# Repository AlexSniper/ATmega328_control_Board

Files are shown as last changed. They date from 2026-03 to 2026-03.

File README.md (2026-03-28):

# ATmega328 Control Board

Custom embedded control board based on the ATmega328PU microcontroller, designed in KiCad and compatible with Arduino firmware.

## Prototype Board
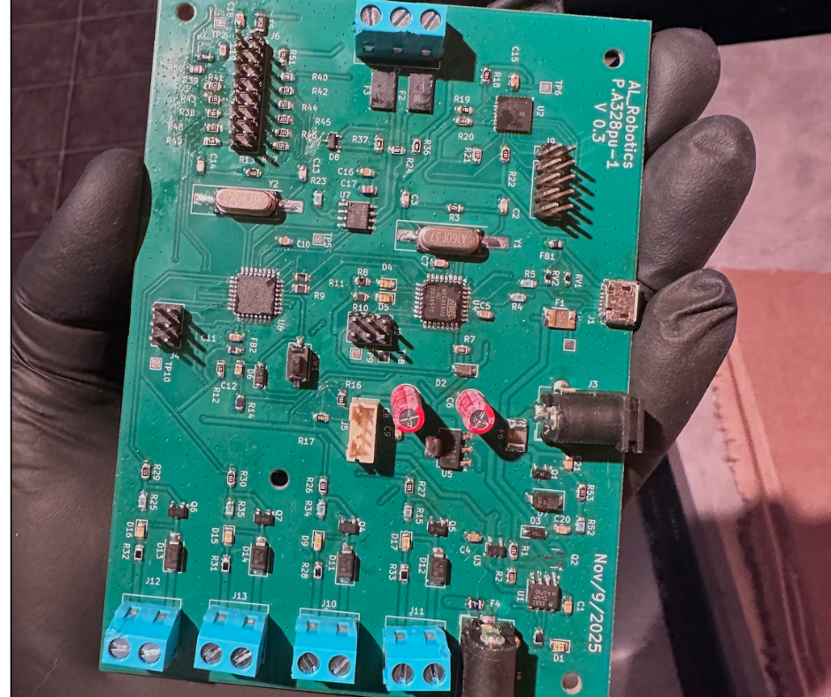
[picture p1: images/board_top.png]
ATmega328 Control Board


## Assembly
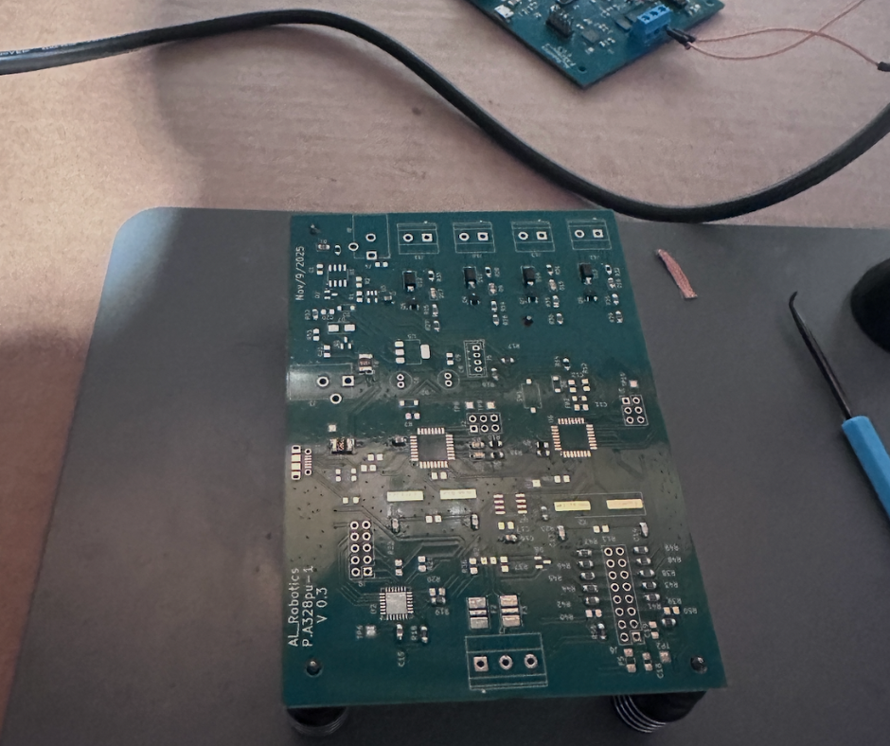
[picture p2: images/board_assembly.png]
Board Assembly


## Testing Setup
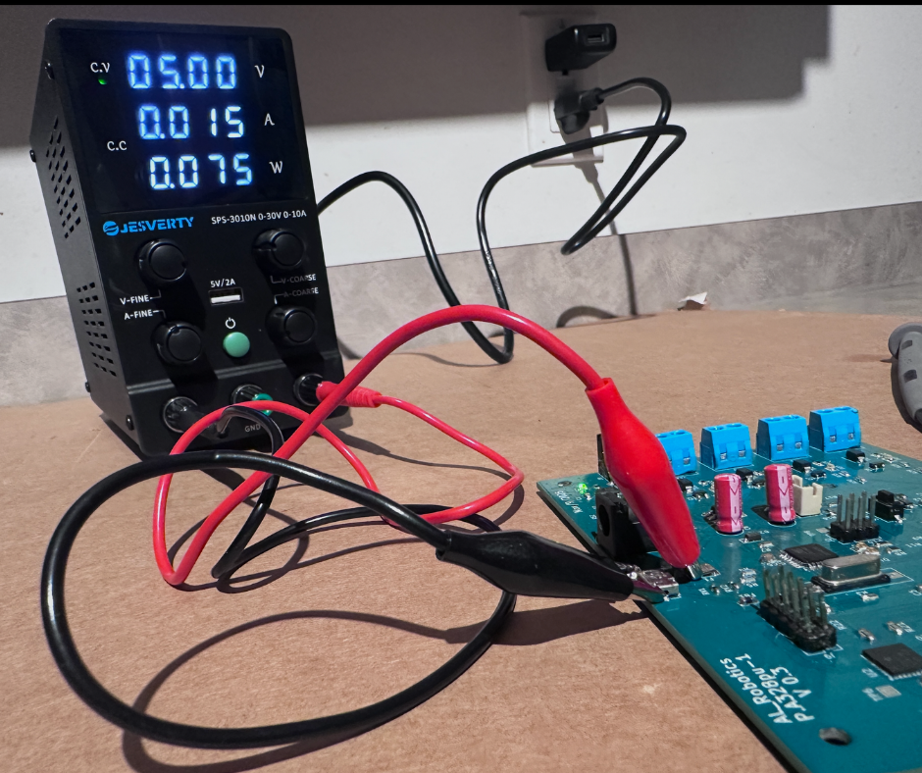
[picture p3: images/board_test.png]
Board Testing


## Clock Verification
External 16 MHz crystal verified using oscilloscope.

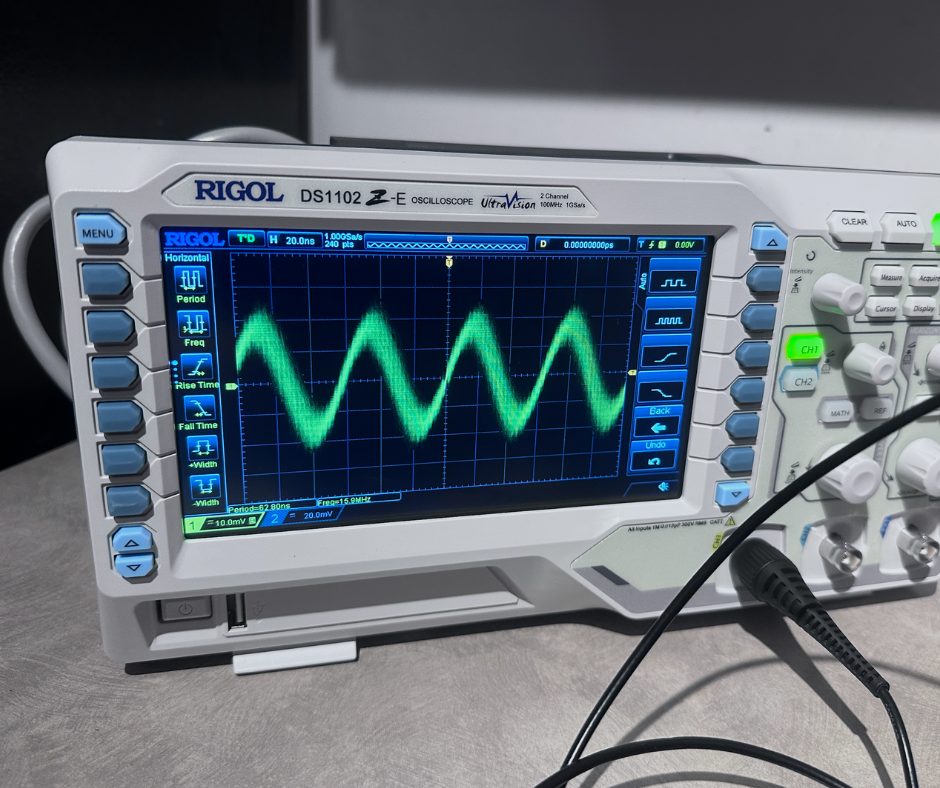
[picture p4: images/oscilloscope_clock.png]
Oscilloscope Clock


## Power Testing
Board powered and tested using laboratory power supply.

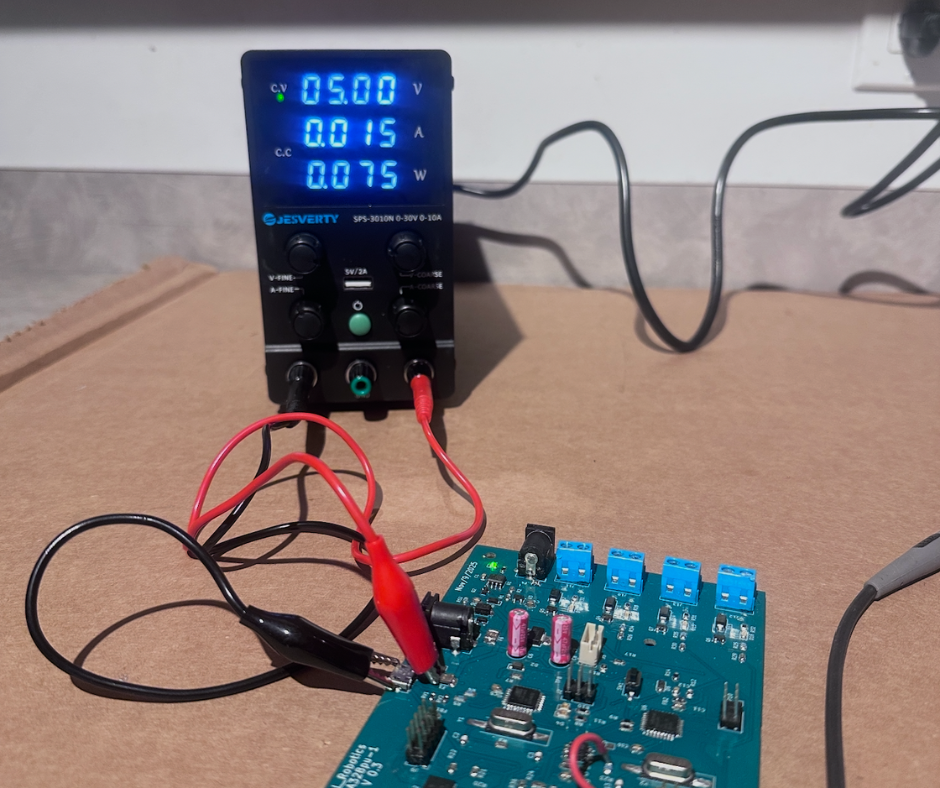
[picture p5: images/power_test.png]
Power Test


## LCD Interface Test
16×2 LCD connected to the ATmega328 board to verify digital IO functionality and firmware operation.
Display output confirms correct microcontroller operation.

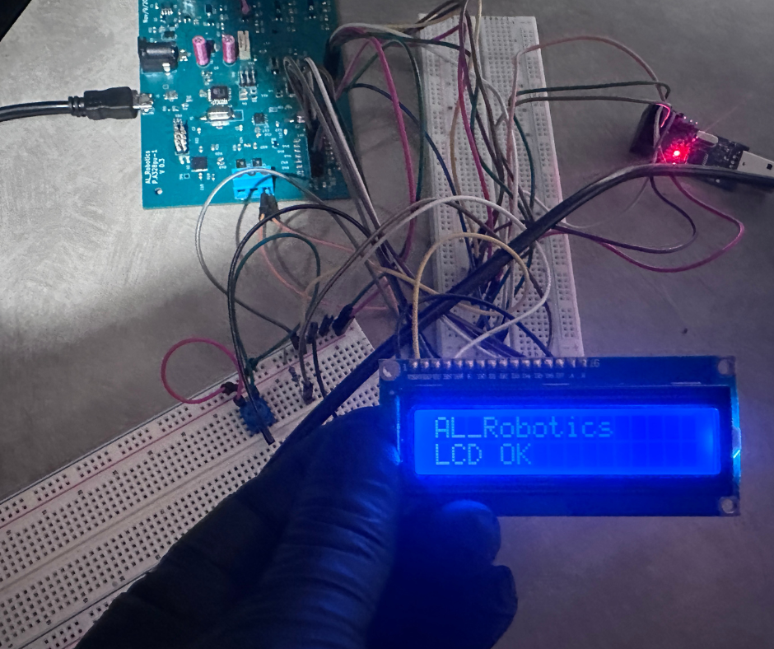
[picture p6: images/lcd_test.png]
Power Test
.png)

### Features
- ATmega328PU microcontroller
- 16 MHz external crystal
- MOSFET output drivers
- Screw terminal IO
- USB programming interface
- External power supply

## Repository structure

hardware – KiCad PCB design  
firmware – Arduino firmware  
gerbers – manufacturing files  
bom – bill of materials  
docs – schematic PDF  
images – hardware prototype photos

## Hardware validation

Clock oscillator verified with oscilloscope.

Board powered and tested using laboratory power supply.

## Hardware Revision History

v0.1 – Initial prototype PCB  
v0.2 – Improved routing and component placement  
v0.3 – Stable prototype, validated clock and power supply

## Author

AL Robotics

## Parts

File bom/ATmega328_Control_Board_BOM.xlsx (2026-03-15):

Reference | Qty | Value | MANUFACTURER # | Link | Footprint
C1,C7,C9,C10,C11,C12,C18,C19,C20 | 9 | 100nF | KAF21BR71H104JM | https://www.mouser.ca/ProductDetail/KYOCERA-AVX/KAF21BR71H104JM?qs=Jm2GQyTW%2FbjLJnSOuM%2FLDw%3D%3D | Capacitor_SMD:C_0805_2012Metric_Pad1.18x1.45mm_HandSolder (https://www.mouser.ca/ProductDetail/KYOCERA-AVX/KAF21BR71H104JM?qs=Jm2GQyTW%2FbjLJnSOuM%2FLDw%3D%3D)
C2,C3,C13,C14 | 4 | 22pF | C0805C220M5HACTU | https://www.mouser.ca/ProductDetail/KEMET/C0805C220M5HACTU?qs=W0yvOO0ixfFRsdd8NMWzNA%3D%3D | Capacitor_SMD:C_0805_2012Metric_Pad1.18x1.45mm_HandSolder (https://www.mouser.ca/ProductDetail/KEMET/C0805C220M5HACTU?qs=W0yvOO0ixfFRsdd8NMWzNA%3D%3D)
C4,C5 | 2 | 1uF | CL21B105KBFNNNE | https://www.mouser.ca/ProductDetail/Samsung-Electro-Mechanics/CL21B105KBFNNNE?qs=yOVawPpwOwmddQEBPU6Y9A%3D%3D | Capacitor_SMD:C_0805_2012Metric_Pad1.18x1.45mm_HandSolder (https://www.mouser.ca/ProductDetail/Samsung-Electro-Mechanics/CL21B105KBFNNNE?qs=yOVawPpwOwmddQEBPU6Y9A%3D%3D)
C6,C8 | 2 | 47uF | 860020472006 | https://www.mouser.ca/ProductDetail/Wurth-Elektronik/860020472006 | Capacitor_THT:C_Radial_D5.0mm_H11.0mm_P2.00mm (https://www.mouser.ca/ProductDetail/Wurth-Elektronik/860020472006)
C15,C16 | 2 | 0.1uF | KAF21BR71H104JM | https://www.mouser.ca/ProductDetail/KYOCERA-AVX/KAF21BR71H104JM?qs=Jm2GQyTW%2FbjLJnSOuM%2FLDw%3D%3D | Capacitor_SMD:C_0805_2012Metric_Pad1.18x1.45mm_HandSolder (https://www.mouser.ca/ProductDetail/KYOCERA-AVX/KAF21BR71H104JM?qs=Jm2GQyTW%2FbjLJnSOuM%2FLDw%3D%3D)
C17 | 1 | 10uF | CL21A106KAYNNNE | https://www.mouser.ca/ProductDetail/Samsung-Electro-Mechanics/CL21A106KAYNNNE?qs=yOVawPpwOwmTXAd4dJtNjA%3D%3D | Capacitor_SMD:C_0805_2012Metric_Pad1.18x1.45mm_HandSolder (https://www.mouser.ca/ProductDetail/Samsung-Electro-Mechanics/CL21A106KAYNNNE?qs=yOVawPpwOwmTXAd4dJtNjA%3D%3D)
C21 | 1 | 10nF | KAF21BR71H103KT | https://www.mouser.ca/ProductDetail/KYOCERA-AVX/KAF21BR71H103KT?qs=OcgtsXO%252B3gvXyW8UIvHhiw%3D%3D | Capacitor_SMD:C_0805_2012Metric_Pad1.18x1.45mm_HandSolder (https://www.mouser.ca/ProductDetail/KYOCERA-AVX/KAF21BR71H103KT?qs=OcgtsXO%252B3gvXyW8UIvHhiw%3D%3D)
D1,D4,D5,D9,D15,D16,D17 | 7 | LED | LTST-C170GKT | https://www.mouser.ca/ProductDetail/LITEON/LTST-C170GKT | Diode_SMD:D_0805_2012Metric_Pad1.15x1.40mm_HandSolder (https://www.mouser.ca/ProductDetail/LITEON/LTST-C170GKT)
D2,D6 | 2 | MMSD4148T1G | MMSD4148T1G | https://www.digikey.ca/en/products/detail/onsemi/MMSD4148T1G/919705 | Diode_SMD:D_SOD-123 (https://www.digikey.ca/en/products/detail/onsemi/MMSD4148T1G/919705)
D3 | 1 | B5819W | B5819W | https://www.digikey.ca/en/products/detail/good-ark-semiconductor/B5819W/18648698 | Diode_SMD:D_SOD-123 (https://www.digikey.ca/en/products/detail/good-ark-semiconductor/B5819W/18648698)
D7 | 1 | SMAJ6.0A | SMAJ6.0A | https://www.digikey.ca/en/products/detail/littelfuse-inc/SMAJ6-0A/762252?gclsrc=aw.ds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 | Diode_SMD:D_SMA (https://www.digikey.ca/en/products/detail/littelfuse-inc/SMAJ6-0A/762252?gclsrc=aw.ds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)
D8 | 1 | CDSOT23-SM712 | CDSOT23-SM712 | https://www.digikey.ca/en/products/detail/bourns-inc/cdsot23-sm712/1630592 | Package_TO_SOT_SMD:SOT-23 (https://www.digikey.ca/en/products/detail/bourns-inc/cdsot23-sm712/1630592)
D11,D12,D13,D14 | 4 | SS14 | SS14 | https://www.mouser.ca/ProductDetail/onsemi-Fairchild/SS14?qs=mVVXn4M53U%252BvrBaFv5vr4w%3D%3D | Diode_SMD:D_SMA (https://www.mouser.ca/ProductDetail/onsemi-Fairchild/SS14?qs=mVVXn4M53U%252BvrBaFv5vr4w%3D%3D)
F1,F6 | 2 | MF-MSMF050-2 | MF-MSMF050-2 | https://www.digikey.ca/en/products/detail/bourns-inc/MF-MSMF050-2/662816?s=N4IgTCBcDaILIDEC0cDKiAMBWDSIF0BfIA | Fuse:Fuse_1812_4532Metric_Pad1.30x3.40mm_HandSolder (https://www.digikey.ca/en/products/detail/bourns-inc/MF-MSMF050-2/662816?s=N4IgTCBcDaILIDEC0cDKiAMBWDSIF0BfIA)
F2,F3 | 2 | TBU-CA-065-200-WH | TBU-CA-065-200-WH | https://www.mouser.ca/ProductDetail/Bourns/TBU-CA065-200-WH?qs=kLtMOTa49OkdVs42fYbv8A%3D%3D | Fuse:Fuse_Bourns_TBU-CA (https://www.mouser.ca/ProductDetail/Bourns/TBU-CA065-200-WH?qs=kLtMOTa49OkdVs42fYbv8A%3D%3D)
F4 | 1 | 0805L200SLTHYR | 0805L200SLTHYR | https://www.digikey.ca/en/products/detail/littelfuse-inc/0805L200SLTHYR/3661958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 | Fuse:Fuse_0805_2012Metric_Pad1.15x1.40mm_HandSolder (https://www.digikey.ca/en/products/detail/littelfuse-inc/0805L200SLTHYR/3661958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)
F5 | 1 | PTSAHT120624V050 | PTSAHT120624V050 | https://www.digikey.ca/en/products/detail/eaton-electronics-division/PTSAHT120624V050/15193498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 | Fuse:Fuse_1206_3216Metric_Pad1.42x1.75mm_HandSolder (https://www.digikey.ca/en/products/detail/eaton-electronics-division/PTSAHT120624V050/15193498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)
FB1,FB2 | 2 | BLM21AG121BH1D | BLM21AG121BH1D | https://www.mouser.ca/ProductDetail/Murata-Electronics/BLM21AG121BH1D?qs=7EBvPakHacVXbDc%252BY3H0nQ%3D%3D | Inductor_SMD:L_0805_2012Metric_Pad1.05x1.20mm_HandSolder (https://www.mouser.ca/ProductDetail/Murata-Electronics/BLM21AG121BH1D?qs=7EBvPakHacVXbDc%252BY3H0nQ%3D%3D)
H1,H2,H3,H4 | 4 | MountingHole |  |  | MountingHole:MountingHole_3.2mm_M3
J1 | 1 | USB_B_Micro | 1050170001 | https://www.digikey.ca/en/products/detail/molex/1050170001/2350832?s=N4IgTCBcDaIIwAYCsC4HYGbiAugXyA | Connector_USB:USB_Micro-B_Molex-105017-0001 (https://www.digikey.ca/en/products/detail/molex/1050170001/2350832?s=N4IgTCBcDaIIwAYCsC4HYGbiAugXyA)
J2,J4 | 2 | AVR-ISP-6 | M20-9980346 | https://www.digikey.ca/en/products/detail/harwin-inc/M20-9980346/3728085 | Connector_PinHeader_2.54mm:PinHeader_2x03_P2.54mm_Vertical (https://www.digikey.ca/en/products/detail/harwin-inc/M20-9980346/3728085)
J3,J8 | 2 | Jack-DC | PJ-102AH | https://www.digikey.ca/en/products/detail/same-sky-formerly-cui-devices/PJ-102AH/408448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 | Connector_BarrelJack:BarrelJack_CUI_PJ-102AH_Horizontal (https://www.digikey.ca/en/products/detail/same-sky-formerly-cui-devices/PJ-102AH/408448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)
J5 | 1 | Conn_01x04_Socket | B4B-PH-K | https://www.digikey.ca/en/products/detail/jst-sales-america-inc/B4B-PH-K/768444?gclsrc=aw.ds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 | Connector_JST:JST_PH_B4B-PH-K_1x04_P2.00mm_Vertical (https://www.digikey.ca/en/products/detail/jst-sales-america-inc/B4B-PH-K/768444?gclsrc=aw.ds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)
J6 | 1 | Conn_02x08_Odd_Even | 10129381-916001BLF | https://www.mouser.ca/ProductDetail/Amphenol-FCI/10129381-916001BLF?qs=0lQeLiL1qyZ57Beoov%2FsZQ%3D%3D | Connector_PinHeader_2.54mm:PinHeader_2x08_P2.54mm_Vertical (https://www.mouser.ca/ProductDetail/Amphenol-FCI/10129381-916001BLF?qs=0lQeLiL1qyZ57Beoov%2FsZQ%3D%3D)
J7 | 1 | Screw_Terminal_01x03 | TB006-508-03BE | https://www.digikey.ca/en/products/detail/same-sky-formerly-cui-devices/TB006-508-03BE/10064116 | TerminalBlock_Phoenix:TerminalBlock_Phoenix_MKDS-1,5-3-5.08_1x03_P5.08mm_Horizontal (https://www.digikey.ca/en/products/detail/same-sky-formerly-cui-devices/TB006-508-03BE/10064116)
J9 | 1 | Conn_02x05_Odd_Even | 61301021121 | https://www.digikey.ca/en/products/detail/w%C3%BCrth-elektronik/61301021121/2508441 | Connector_PinHeader_2.54mm:PinHeader_2x05_P2.54mm_Vertical (https://www.digikey.ca/en/products/detail/w%C3%BCrth-elektronik/61301021121/2508441)
J10,J11,J12,J13 | 4 | Screw_Terminal_01x02 | TB006-508-02BE | https://www.digikey.ca/en/products/detail/same-sky-formerly-cui-devices/TB006-508-02BE/10064115 | TerminalBlock_Phoenix:TerminalBlock_Phoenix_MKDS-1,5-2-5.08_1x02_P5.08mm_Horizontal (https://www.digikey.ca/en/products/detail/same-sky-formerly-cui-devices/TB006-508-02BE/10064115)
Q1 | 1 | DMG2305UX | DMG2305UX-7 | https://www.digikey.ca/en/products/detail/diodes-incorporated/DMG2305UX-7/4340667 | Package_TO_SOT_SMD:SOT-23 (https://www.digikey.ca/en/products/detail/diodes-incorporated/DMG2305UX-7/4340667)
Q2 | 1 | FDN340P | FDN340P | https://www.digikey.ca/en/products/detail/umw/FDN340P/16705911 | Package_TO_SOT_SMD:SOT-23 (https://www.digikey.ca/en/products/detail/umw/FDN340P/16705911)
Q4,Q5,Q6,Q7 | 4 | AO3400A | AO3400A | https://www.digikey.ca/en/products/detail/alpha-omega-semiconductor-inc/AO3400A/1855772 | Package_TO_SOT_SMD:SOT-23 (https://www.digikey.ca/en/products/detail/alpha-omega-semiconductor-inc/AO3400A/1855772)
R1,R2,R12 | 3 | 10k | CR0805-JW-103ELF | https://www.mouser.ca/ProductDetail/Bourns/CR0805-JW-103ELF?qs=sGAEpiMZZMtlubZbdhIBIBdtMJZUNN5bjlV5FNdlAQE%3D | Resistor_SMD:R_0805_2012Metric_Pad1.20x1.40mm_HandSolder (https://www.mouser.ca/ProductDetail/Bourns/CR0805-JW-103ELF?qs=sGAEpiMZZMtlubZbdhIBIBdtMJZUNN5bjlV5FNdlAQE%3D)
R3,R13 | 2 | 1M | CRGCQ0805F1M0 | https://www.mouser.ca/ProductDetail/TE-Connectivity-Holsworthy/CRGCQ0805F1M0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 | Resistor_SMD:R_0805_2012Metric_Pad1.20x1.40mm_HandSolder (https://www.mouser.ca/ProductDetail/TE-Connectivity-Holsworthy/CRGCQ0805F1M0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)
R4,R5 | 2 | 22 | RK73H2ATTDD22R0F | https://www.mouser.ca/ProductDetail/KOA-Speer/RK73H2ATTDD22R0F | Resistor_SMD:R_0805_2012Metric_Pad1.20x1.40mm_HandSolder (https://www.mouser.ca/ProductDetail/KOA-Speer/RK73H2ATTDD22R0F)
R6,R8,R9,R10,R11,R14 | 6 | 1k | CRCW08051K00FKTAHP | https://www.mouser.ca/ProductDetail/Vishay/CRCW08051K00FKTAHP | Resistor_SMD:R_0805_2012Metric_Pad1.20x1.40mm_HandSolder (https://www.mouser.ca/ProductDetail/Vishay/CRCW08051K00FKTAHP)
R7,R20,R21,R22 | 4 | 10K | CR0805-JW-103ELF | https://www.mouser.ca/ProductDetail/Bourns/CR0805-JW-103ELF?qs=sGAEpiMZZMtlubZbdhIBIBdtMJZUNN5bjlV5FNdlAQE%3D | Resistor_SMD:R_0805_2012Metric_Pad1.20x1.40mm_HandSolder (https://www.mouser.ca/ProductDetail/Bourns/CR0805-JW-103ELF?qs=sGAEpiMZZMtlubZbdhIBIBdtMJZUNN5bjlV5FNdlAQE%3D)
R15,R23,R25,R34,R35,R52 | 6 | 100K | RK73H2ATTE1003F | https://www.mouser.ca/ProductDetail/KOA-Speer/RK73H2ATTE1003F | Resistor_SMD:R_0805_2012Metric_Pad1.20x1.40mm_HandSolder (https://www.mouser.ca/ProductDetail/KOA-Speer/RK73H2ATTE1003F)
R16,R17,R18,R19,R50,R51 | 6 | 4K7 | CRCW08054K70FKEAC | https://www.digikey.ca/en/products/detail/vishay-dale/CRCW08054K70FKEAC/7928553 | Resistor_SMD:R_0805_2012Metric_Pad1.20x1.40mm_HandSolder (https://www.digikey.ca/en/products/detail/vishay-dale/CRCW08054K70FKEAC/7928553)
R24 | 1 | 120 | RMCF0805FT120R | https://www.digikey.ca/en/products/detail/stackpole-electronics-inc/RMCF0805FT120R/1712658 | Resistor_SMD:R_0805_2012Metric_Pad1.20x1.40mm_HandSolder (https://www.digikey.ca/en/products/detail/stackpole-electronics-inc/RMCF0805FT120R/1712658)
R26,R27,R29,R30,R38,R41,R42,R43,R44,R45,R46,R47,R48,R49,R53 | 15 | 100 | ERA-6AEB101V | https://www.digikey.ca/en/products/detail/panasonic-electronic-components/ERA-6AEB101V/1465724 | Resistor_SMD:R_0805_2012Metric_Pad1.20x1.40mm_HandSolder (https://www.digikey.ca/en/products/detail/panasonic-electronic-components/ERA-6AEB101V/1465724)
R28,R31,R32,R33 | 4 | 1K | CRCW08051K00FKEA | https://www.digikey.ca/en/products/detail/vishay-dale/CRCW08051K00FKEA/1175637 | Resistor_SMD:R_0805_2012Metric_Pad1.20x1.40mm_HandSolder (https://www.digikey.ca/en/products/detail/vishay-dale/CRCW08051K00FKEA/1175637)
R36,R37 | 2 | 680 | ERJ-6GEYJ681V | https://www.digikey.ca/en/products/detail/panasonic-electronic-components/ERJ-6GEYJ681V/89778 | Resistor_SMD:R_0805_2012Metric_Pad1.20x1.40mm_HandSolder (https://www.digikey.ca/en/products/detail/panasonic-electronic-components/ERJ-6GEYJ681V/89778)
R39,R40 | 2 | 47 | RMCF0805JT47R0 | https://www.digikey.ca/en/products/detail/stackpole-electronics-inc/RMCF0805JT47R0/1757848 | Resistor_SMD:R_0805_2012Metric_Pad1.20x1.40mm_HandSolder (https://www.digikey.ca/en/products/detail/stackpole-electronics-inc/RMCF0805JT47R0/1757848)
RV1,RV2 | 2 | CG0603MLC-05E | CG0603MLC-05E | https://www.digikey.ca/en/products/detail/bourns-inc/CG0603MLC-05E/2538084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 | Capacitor_SMD:C_0603_1608Metric_Pad1.08x0.95mm_HandSolder (https://www.digikey.ca/en/products/detail/bourns-inc/CG0603MLC-05E/2538084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)
SW1 | 1 | SW_Push | PTS636 SP50 SMTR LFS | https://www.mouser.ca/ProductDetail/CK/PTS636SP50SMTR-LFS?qs=jcD%2FCkGBYePnW2Z6HXXTjA%3D%3D | Button_Switch_SMD:SW_Tactile_SPST_NO_Straight_CK_PTS636Sx25SMTRLFS (https://www.mouser.ca/ProductDetail/CK/PTS636SP50SMTR-LFS?qs=jcD%2FCkGBYePnW2Z6HXXTjA%3D%3D)
TP1,TP2 | 2 | TP_5V |  |  | TestPoint:TestPoint_Pad_1.5x1.5mm
TP5 | 1 | TP5_5V |  |  | TestPoint:TestPoint_Pad_1.5x1.5mm
TP6 | 1 | TP_3.3V |  |  | TestPoint:TestPoint_Pad_1.5x1.5mm
TP8 | 1 | TP8_5V |  |  | TestPoint:TestPoint_Pad_1.5x1.5mm
TP9 | 1 | TP9_GND |  |  | TestPoint:TestPoint_Pad_1.5x1.5mm
TP10 | 1 | TP10_5V |  |  | TestPoint:TestPoint_Pad_1.5x1.5mm
U1 | 1 | LMV358 | LMV358IDR | https://www.digikey.ca/en/products/detail/texas-instruments/LMV358IDR/381251 | Package_SO:SOIC-8_3.9x4.9mm_P1.27mm (https://www.digikey.ca/en/products/detail/texas-instruments/LMV358IDR/381251)
U2 | 1 | MCP23017_ML | MCP23017-E/ML | https://www.digikey.ca/en/products/detail/microchip-technology/mcp23017-e-ml/894270 | Package_DFN_QFN:QFN-28-1EP_6x6mm_P0.65mm_EP4.25x4.25mm (https://www.digikey.ca/en/products/detail/microchip-technology/mcp23017-e-ml/894270)
U3 | 1 | LP2985-3.3 | LP2985-33DBVR | https://www.digikey.ca/en/products/detail/texas-instruments/LP2985-33DBVR/809759 | Package_TO_SOT_SMD:SOT-23-5 (https://www.digikey.ca/en/products/detail/texas-instruments/LP2985-33DBVR/809759)
U4 | 1 | ATmega16U2-A | ATMEGA16U2-AU | https://www.digikey.ca/en/products/detail/microchip-technology/ATMEGA16U2-AU/2050947 | Package_QFP:TQFP-32_7x7mm_P0.8mm (https://www.digikey.ca/en/products/detail/microchip-technology/ATMEGA16U2-AU/2050947)
U5 | 1 | NCP1117 | AMS1117-5.0 SOT-223 | https://www.digikey.ca/en/products/detail/shenzhen-slkormicro-semicon-co-ltd/ams1117-5-0-sot-223/22204997 | Package_TO_SOT_SMD:SOT-223-3_TabPin2 (https://www.digikey.ca/en/products/detail/shenzhen-slkormicro-semicon-co-ltd/ams1117-5-0-sot-223/22204997)
U6 | 1 | ATmega328PB-A | ATMEGA328PB-AU | https://www.digikey.ca/en/products/detail/microchip-technology/ATMEGA328PB-AU/5638812 | Package_QFP:TQFP-32_7x7mm_P0.8mm (https://www.digikey.ca/en/products/detail/microchip-technology/ATMEGA328PB-AU/5638812)
U7 | 1 | MAX485E | MAX485ECSA+T | https://www.digikey.ca/en/products/detail/analog-devices-inc-maxim-integrated/MAX485ECSA-T/1499504 | Package_SO:SOIC-8_3.9x4.9mm_P1.27mm (https://www.digikey.ca/en/products/detail/analog-devices-inc-maxim-integrated/MAX485ECSA-T/1499504)
Y1,Y2 | 2 | ABLS-16.000MHZ-D-4-T | ABLS-16.000MHZ-D-4-T | https://www.digikey.ca/en/products/detail/abracon-llc/ABLS-16-000MHZ-D-4-T/5980032 | Crystal:Crystal_SMD_HC49-SD_HandSoldering (https://www.digikey.ca/en/products/detail/abracon-llc/ABLS-16-000MHZ-D-4-T/5980032)

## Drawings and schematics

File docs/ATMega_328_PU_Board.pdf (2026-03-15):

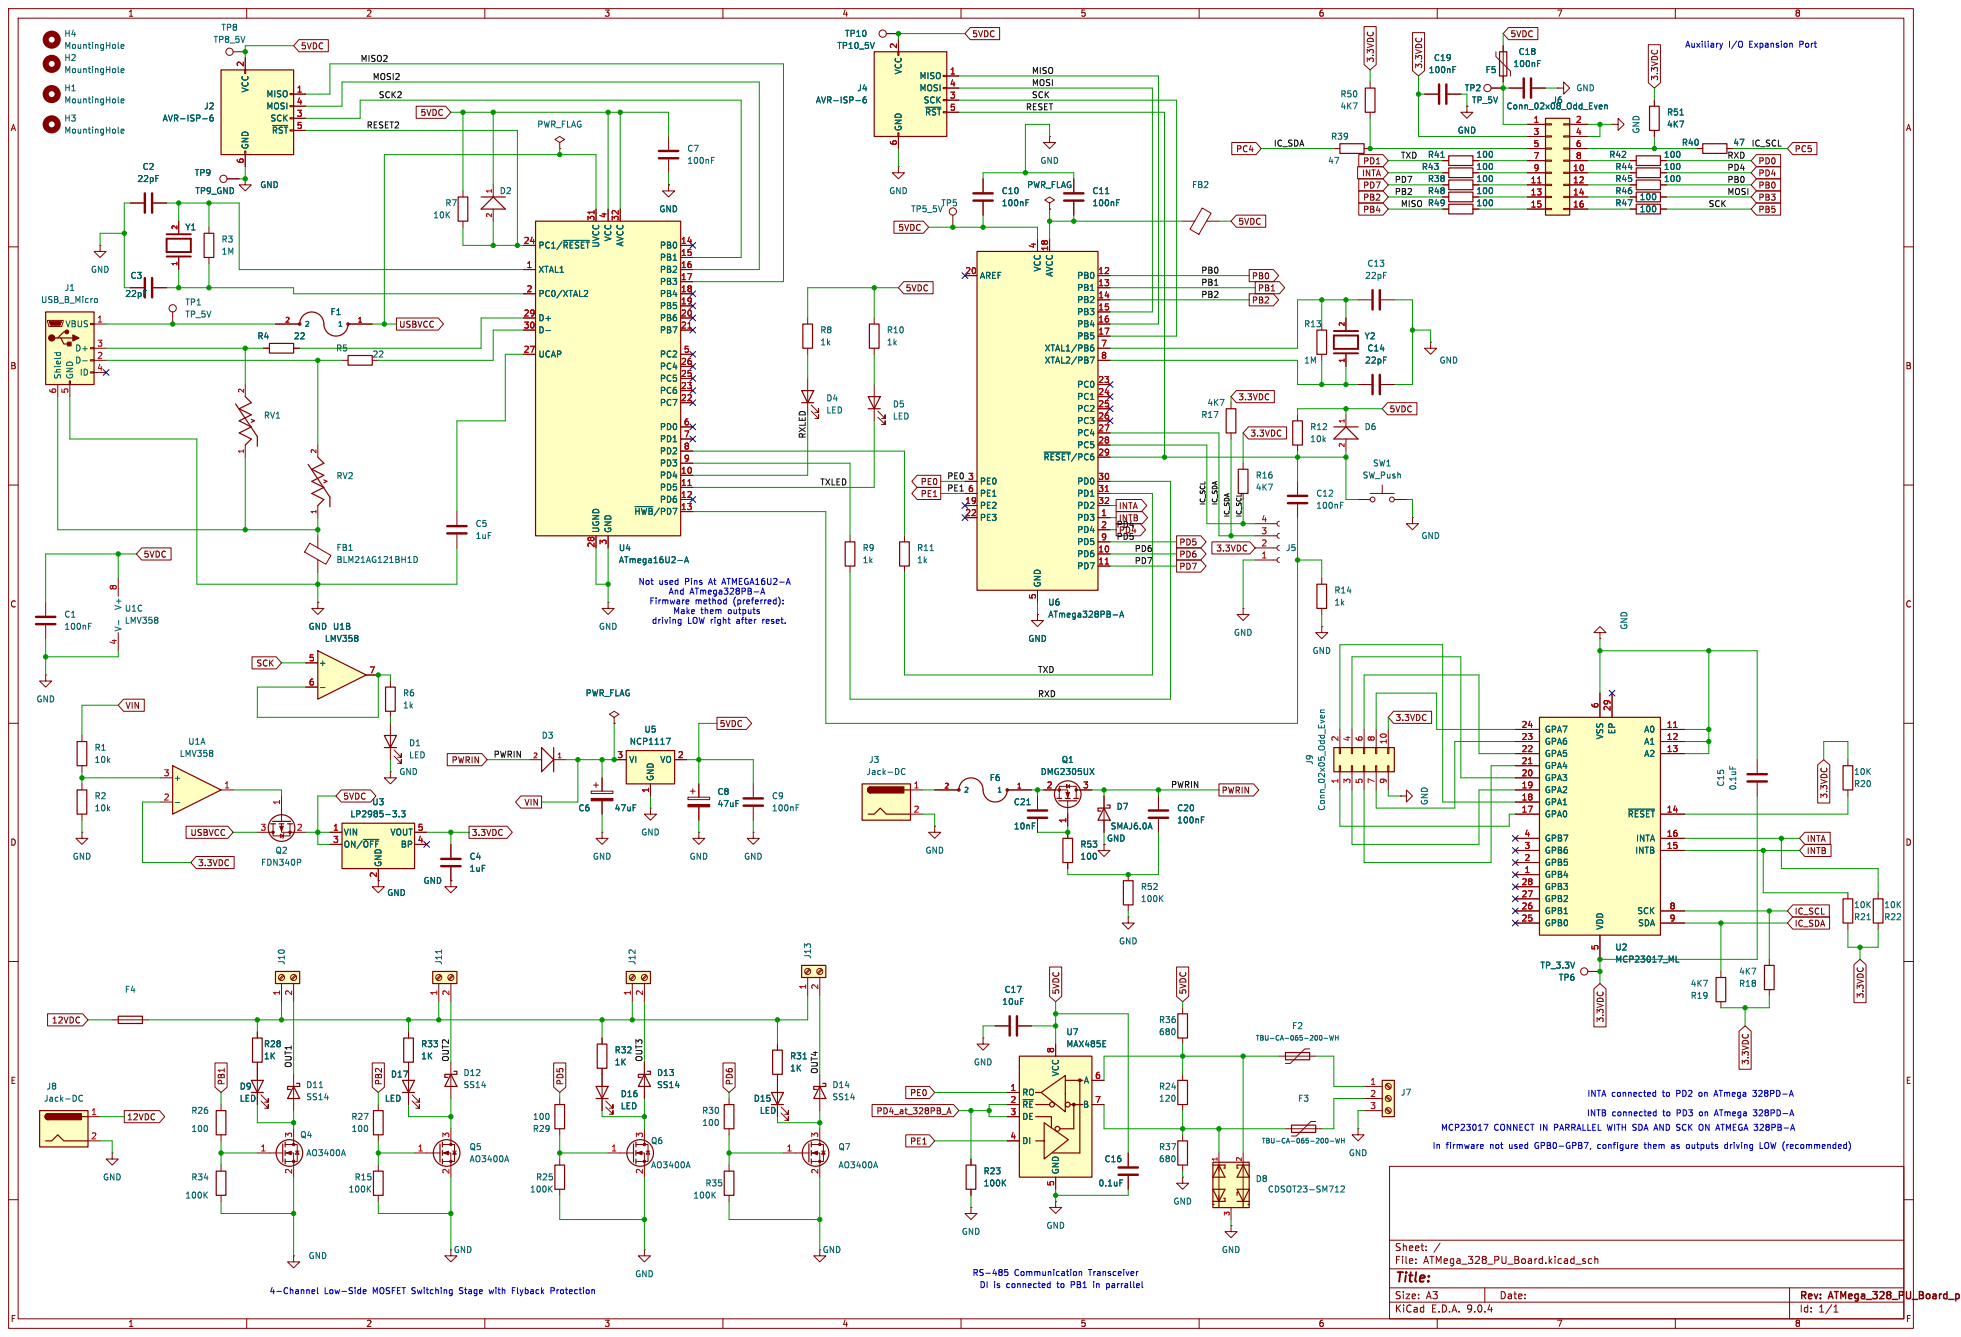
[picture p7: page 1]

6 MISO 1 MOSI 4 SCK 3 ~{RST}5 TP10 TP10_5V U1B

6 MISO 1 MOSI 4 SCK 3 ~{RST}5

6 MISO 1 MOSI 4 SCK 3 ~{RST}5 GND GND

Not used Pins At ATMEGA16U2-A
And ATmega328PB-A
Firmware method (preferred): Make them outputs driving LOW right after reset.

Id: 1/1 Title: File: ATMega_328_PU_Board.kicad_sch Sheet: / 1

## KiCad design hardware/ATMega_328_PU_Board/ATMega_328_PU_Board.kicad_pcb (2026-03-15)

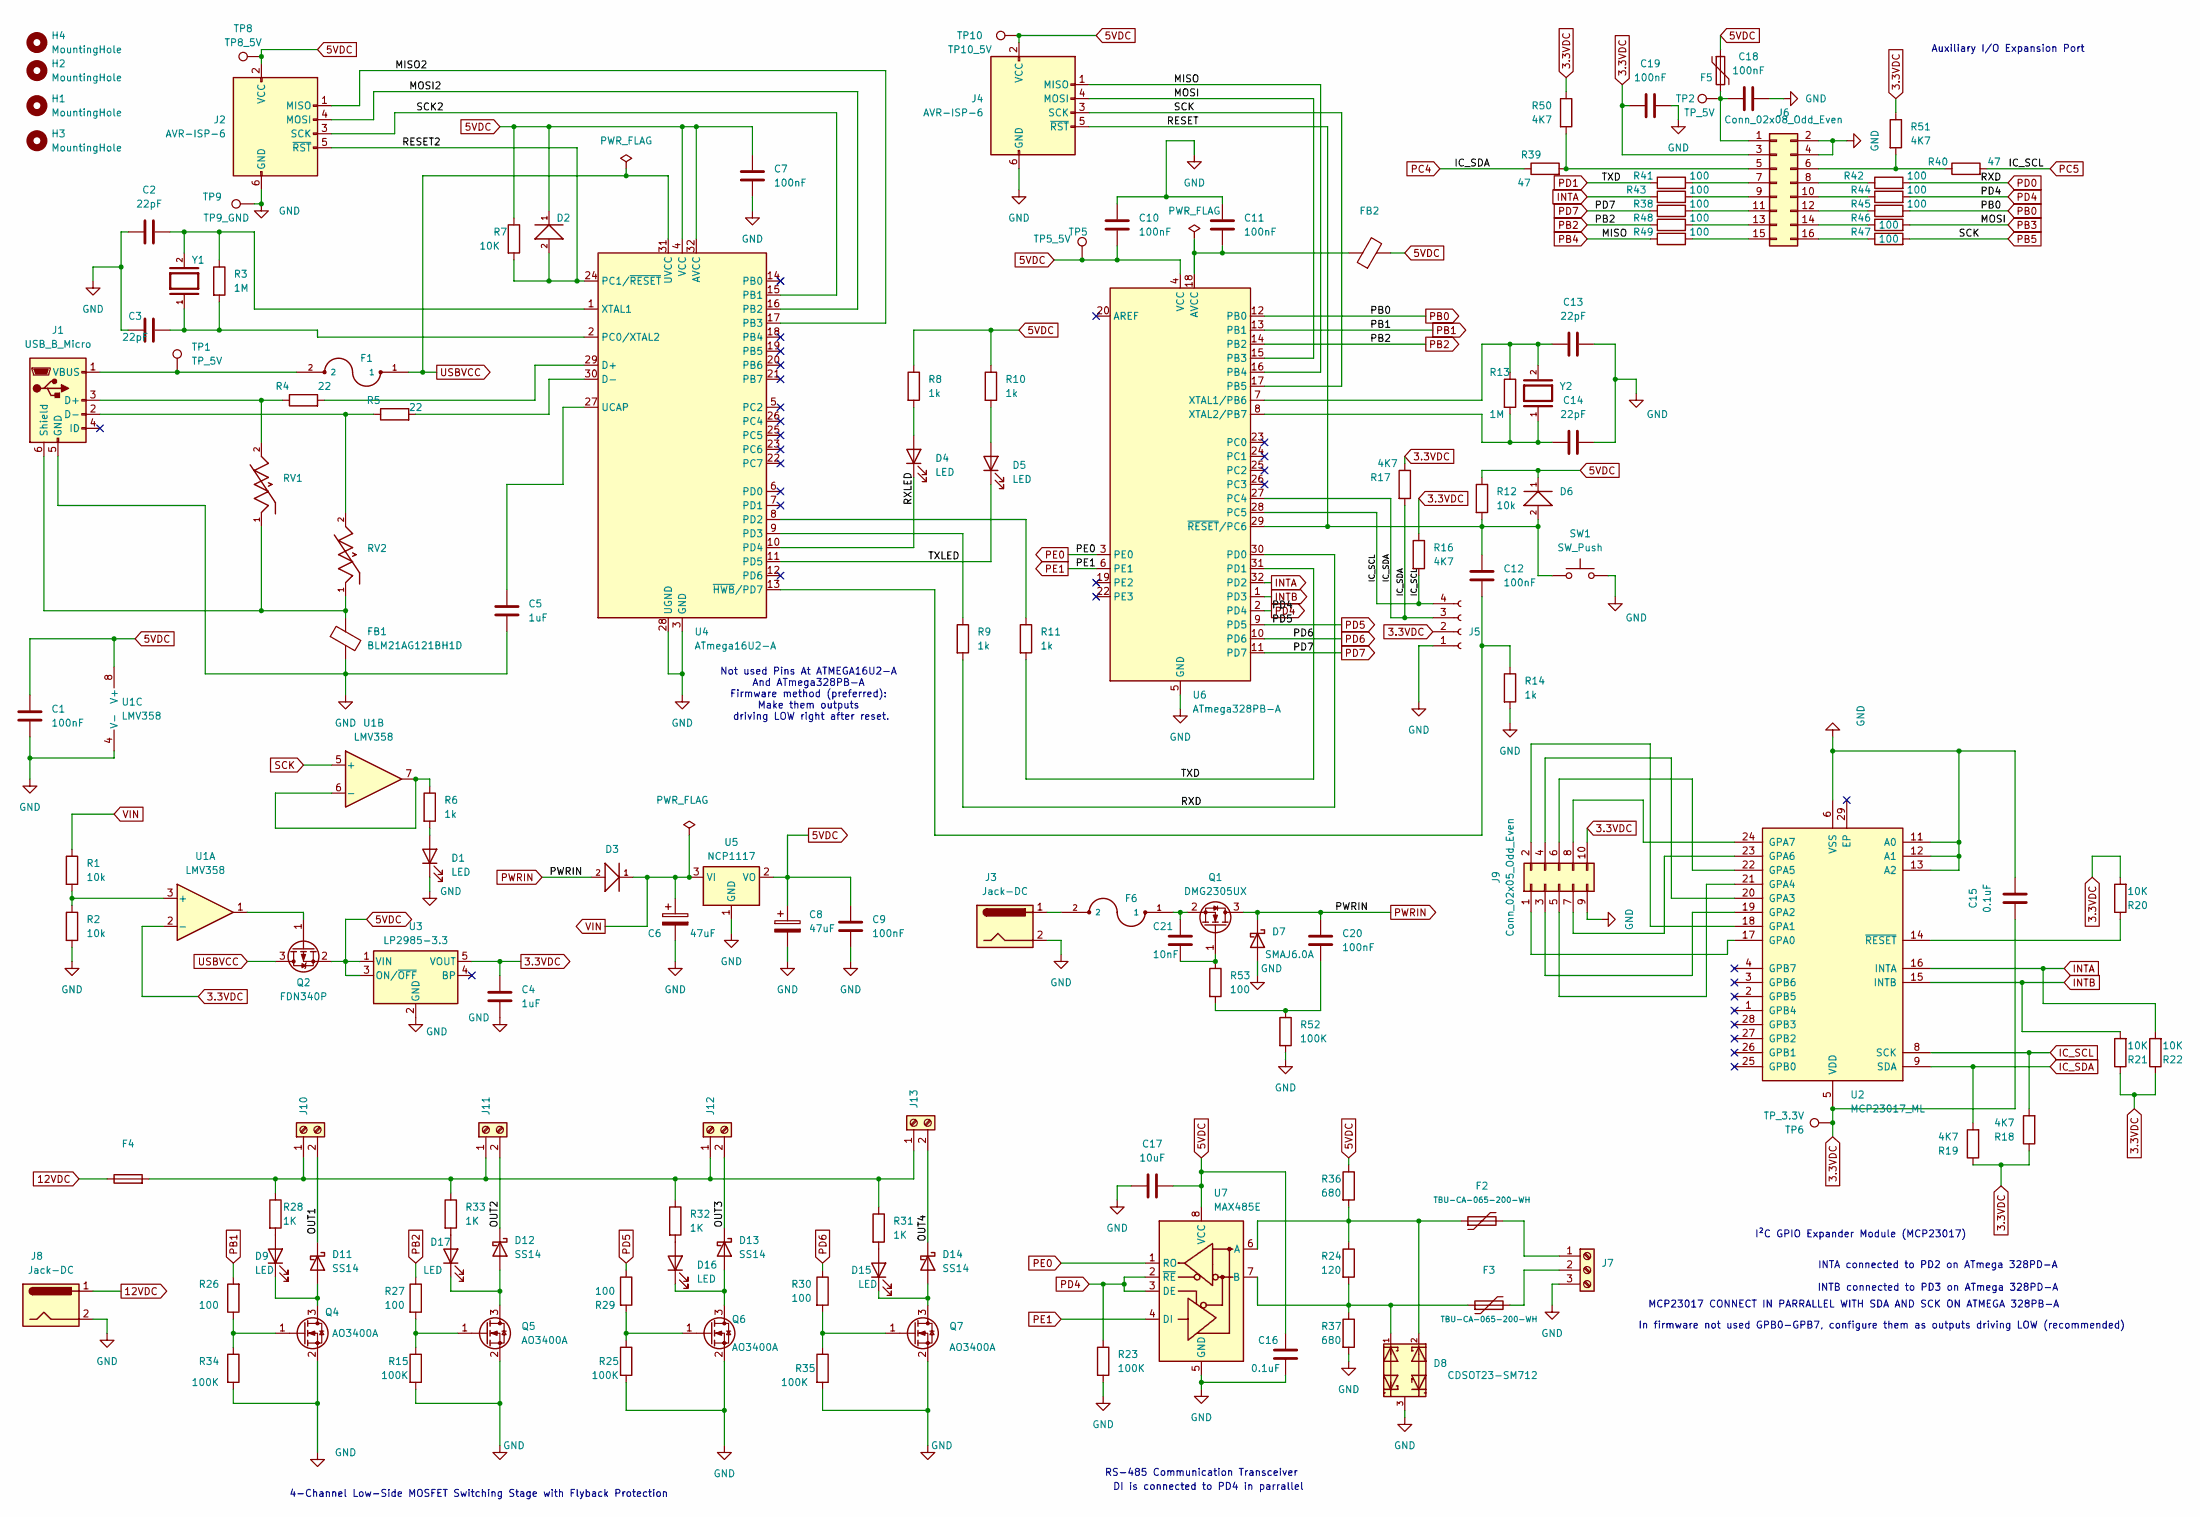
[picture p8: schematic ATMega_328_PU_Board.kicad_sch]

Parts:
C1, C7, C9, C10, C11, C12, C18, C19, C20: 100nF; C_0805_2012Metric_Pad1.18x1.45mm_HandSolder
C2, C3, C13, C14: 22pF; C_0805_2012Metric_Pad1.18x1.45mm_HandSolder
C4, C5: 1uF; C_0805_2012Metric_Pad1.18x1.45mm_HandSolder
C6, C8: 47uF; C_Radial_D5.0mm_H11.0mm_P2.00mm
C15, C16: 0.1uF; C_0805_2012Metric_Pad1.18x1.45mm_HandSolder
C17: 10uF; C_0805_2012Metric_Pad1.18x1.45mm_HandSolder
C21: 10nF; C_0805_2012Metric_Pad1.18x1.45mm_HandSolder
D1, D4, D5, D9, D15, D16, D17: LED; D_0805_2012Metric_Pad1.15x1.40mm_HandSolder
D2, D6: MMSD4148T1G; D_SOD-123; MPN CD1206-S01575
D3: B5819W; D_SOD-123; MPN CD1206-S01575
D7: SMAJ6.0A; D_SMA
D8: CDSOT23-SM712; SOT-23
D11, D12, D13, D14: SS14; D_SMA
F1, F6: MF-MSMF050-2; Fuse_1812_4532Metric_Pad1.30x3.40mm_HandSolder
F2, F3: TBU-CA-065-200-WH; Fuse_Bourns_TBU-CA
F4: 0805L200SLTHYR; Fuse_0805_2012Metric_Pad1.15x1.40mm_HandSolder
F5: PTSAHT120624V050; Fuse_1206_3216Metric_Pad1.42x1.75mm_HandSolder
FB1, FB2: BLM21AG121BH1D; L_0805_2012Metric_Pad1.05x1.20mm_HandSolder
H1, H2, H3, H4: MountingHole; MountingHole_3.2mm_M3
J1: USB_B_Micro; USB_Micro-B_Molex-105017-0001
J2, J4: AVR-ISP-6; PinHeader_2x03_P2.54mm_Vertical
J3, J8: Jack-DC; BarrelJack_CUI_PJ-102AH_Horizontal
J5: Conn_01x04_Socket; JST_PH_B4B-PH-K_1x04_P2.00mm_Vertical
J6: Conn_02x08_Odd_Even; PinHeader_2x08_P2.54mm_Vertical
J7: Screw_Terminal_01x03; TerminalBlock_Phoenix_MKDS-1,5-3-5.08_1x03_P5.08mm_Horizont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
J9: Conn_02x05_Odd_Even; PinHeader_2x05_P2.54mm_Vertical
J10, J11, J12, J13: Screw_Terminal_01x02; TerminalBlock_Phoenix_MKDS-1,5-2-5.08_1x02_P5.08mm_Horizont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
Q1: DMG2305UX; SOT-23
Q2: FDN340P; SOT-23
Q4, Q5, Q6, Q7: AO3400A; SOT-23
R1, R2, R12: 10k; R_0805_2012Metric_Pad1.20x1.40mm_HandSolder
R3, R13: 1M; R_0805_2012Metric_Pad1.20x1.40mm_HandSolder
R4, R5: 22; R_0805_2012Metric_Pad1.20x1.40mm_HandSolder
R6, R8, R9, R10, R11, R14: 1k; R_0805_2012Metric_Pad1.20x1.40mm_HandSolder
R7, R20, R21, R22: 10K; R_0805_2012Metric_Pad1.20x1.40mm_HandSolder
R15, R23, R25, R34, R35, R52: 100K; R_0805_2012Metric_Pad1.20x1.40mm_HandSolder
R16, R17, R18, R19, R50, R51: 4K7; R_0805_2012Metric_Pad1.20x1.40mm_HandSolder
R24: 120; R_0805_2012Metric_Pad1.20x1.40mm_HandSolder
R26, R27, R29, R30, R38, R41, R42, R43, R44, R45, R46, R47, R48, R49, R53: 100; R_0805_2012Metric_Pad1.20x1.40mm_HandSolder
R28, R31, R32, R33: 1K; R_0805_2012Metric_Pad1.20x1.40mm_HandSolder
R36, R37: 680; R_0805_2012Metric_Pad1.20x1.40mm_HandSolder
R39, R40: 47; R_0805_2012Metric_Pad1.20x1.40mm_HandSolder
RV1, RV2: CG0603MLC-05E; C_0603_1608Metric_Pad1.08x0.95mm_HandSolder; PARTREV E
SW1: SW_Push; SW_Tactile_SPST_NO_Straight_CK_PTS636Sx25SMTRLFS
TP1, TP2: TP_5V; TestPoint_Pad_1.5x1.5mm
TP5: TP5_5V; TestPoint_Pad_1.5x1.5mm
TP6: TP_3.3V; TestPoint_Pad_1.5x1.5mm
TP8: TP8_5V; TestPoint_Pad_1.5x1.5mm
TP9: TP9_GND; TestPoint_Pad_1.5x1.5mm
TP10: TP10_5V; TestPoint_Pad_1.5x1.5mm
U1: LMV358; SOIC-8_3.9x4.9mm_P1.27mm
U2: MCP23017_ML; QFN-28-1EP_6x6mm_P0.65mm_EP4.25x4.25mm
U3: LP2985-3.3; SOT-23-5
U4: ATmega16U2-A; TQFP-32_7x7mm_P0.8mm
U5: NCP1117; SOT-223-3_TabPin2
U6: ATmega328PB-A; TQFP-32_7x7mm_P0.8mm
U7: MAX485E; SOIC-8_3.9x4.9mm_P1.27mm
Y1, Y2: ABLS-16.000MHZ-D-4-T; Crystal_SMD_HC49-SD_HandSoldering; PARTREV 02.16.2021

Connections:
3.3VDC: C4.1, C15.1, C19.2, J5.2, J6.3, J9.10, R16.1, R17.1, R18.1, R19.1, R20.2, R21.1, R22.1, R50.1, R51.1, TP6.1, U1.2 (-), U2.5 (VDD), U3.5 (VOUT)
5VDC: C1.1, C7.1, C8.1, C9.1, C10.2, C16.1, C17.2, D2.1, D6.1, F5.1, FB2.2, J2.2 (VCC), J4.2 (VCC), Q2.2 (S), R7.1, R8.1, R10.1, R12.1, R36.1, TP5.1, TP8.1, TP10.1, U1.8 (V+), U3.1 (VIN), U3.3 (ON/~OFF), U4.4 (VCC), U4.32 (AVCC), U5.2 (VO), U6.4 (VCC), U7.8 (VCC)
12VDC: F4.1, J8.1
/MISO2: J2.1 (MISO), U4.17 (PB3)
/MOSI2: J2.4 (MOSI), U4.16 (PB2)
/OUT1: D11.1 (K), J10.2
/OUT2: D12.1 (K), J11.2
/OUT3: D13.1 (K), J12.2
/OUT4: D14.1 (K), J13.2
/RESET: C12.1, D6.2, J4.5 (~RST), R12.2, SW1.1, U6.29 (~RESET/PC6)
/RESET2: D2.2, J2.5 (~RST), R7.2, U4.24 (PC1/~RESET)
/RXLED: D4.1 (K), U4.10 (PD4)
/SCK2: J2.3 (SCK), U4.15 (PB1)
/TXLED: D5.1 (K), U4.11 (PD5)
GND: C1.2, C2.1, C3.1, C4.2, C5.2, C6.2, C7.2, C8.2, C9.2, C10.1, C11.1, C13.2, C14.2, C15.2, C16.2, C17.1, C18.2, C19.1, D1.1 (K), D7.2 (A), D8.3, FB1.2, J1.5 (GND), J2.6 (GND), J3.2, J4.6 (GND), J5.1, J6.2, J6.4, J7.3, J8.2, J9.9, Q4.2 (S), Q5.2 (S), Q6.2 (S), Q7.2 (S), R2.2, R14.2, R15.2, R23.2, R25.2, R34.2, R35.2, R37.2, R52.2, SW1.2, TP9.1, U1.4 (V-), U2.6 (VSS), U2.11 (A0), U2.12 (A1), U2.13 (A2), U3.2 (GND), U4.3 (GND), U4.28 (UGND), U5.1 (GND), U6.5 (GND), U6.21 (GND), U7.5 (GND)
IC_SCL: J5.4, R16.2, R18.2, R40.2, U2.8 (SCK), U6.28 (PC5)
IC_SDA: J5.3, R17.2, R19.2, R39.1, U2.9 (SDA), U6.27 (PC4)
INTA: R22.2, R43.1, U2.16 (INTA), U6.32 (PD2)
INTB: R21.2, U2.15 (INTB), U6.1 (PD3)
unnamed: C20.2, R52.1, R53.2
unnamed: D1.2 (A), R6.2
unnamed: D4.2 (A), R8.2
unnamed: D5.2 (A), R10.2
unnamed: D9.2 (A), R28.2
unnamed: D9.1 (K), D11.2 (A), Q4.3 (D)
unnamed: D12.2 (A), D17.1 (K), Q5.3 (D)
unnamed: D13.2 (A), D16.1 (K), Q6.3 (D)
unnamed: D14.2 (A), D15.1 (K), Q7.3 (D)
unnamed: D15.2 (A), R31.2
unnamed: D16.2 (A), R32.2
unnamed: D17.2 (A), R33.2
unnamed: F6.2, J3.1
unnamed: J1.3 (D+), R4.1, RV1.2
unnamed: J1.2 (D-), R5.1, RV2.2
unnamed: FB1.1, J1.6 (Shield), RV1.1, RV2.1
unnamed: F1.2, J1.1 (VBUS), TP1.1
unnamed: C18.1, F5.2, J6.1, TP2.1
unnamed: J6.5, R39.2, R50.2
unnamed: J6.6, R40.1, R51.2
unnamed: J6.7, R41.2
unnamed: J6.8, R42.1
unnamed: J6.9, R43.2
unnamed: J6.10, R44.1
unnamed: J6.11, R38.2
unnamed: J6.12, R45.1
unnamed: J6.13, R48.2
unnamed: J6.14, R46.1
unnamed: J6.15, R49.2
unnamed: J6.16, R47.1
unnamed: F2.3, J7.1
unnamed: F3.3, J7.2
unnamed: J9.1, U2.17 (GPA0)
unnamed: J9.2, U2.18 (GPA1)
unnamed: J9.3, U2.19 (GPA2)
unnamed: J9.4, U2.20 (GPA3)
unnamed: J9.5, U2.21 (GPA4)
unnamed: J9.6, U2.22 (GPA5)
unnamed: J9.7, U2.23 (GPA6)
unnamed: J9.8, U2.24 (GPA7)
unnamed: F4.2, J10.1, J11.1, J12.1, J13.1, R28.1, R31.1, R32.1, R33.1
unnamed: C21.2, Q1.1 (G), R53.1
unnamed: C21.1, F6.1, Q1.2 (S)
unnamed: Q2.1 (G), U1.1
unnamed: Q4.1 (G), R26.1, R34.1
unnamed: Q5.1 (G), R15.1, R27.2
unnamed: Q6.1 (G), R25.1, R29.2
unnamed: Q7.1 (G), R30.2, R35.1
unnamed: R1.2, R2.1, U1.3 (+)
unnamed: R6.1, U1.6 (-), U1.7
unnamed: R20.1, U2.14 (~RESET)
unnamed: R4.2, U4.29 (D+)
unnamed: R5.2, U4.30 (D-)
unnamed: C3.2, R3.2, U4.2 (PC0/XTAL2), Y1.1
unnamed: R11.1, U4.8 (PD2)
unnamed: R9.1, U4.9 (PD3)
unnamed: C5.1, U4.27 (UCAP)
unnamed: C2.2, R3.1, U4.1 (XTAL1), Y1.2
unnamed: C12.2, R14.1, U4.13 (~HWB/PD7)
unnamed: C11.2, FB2.1, U6.18 (AVCC)
unnamed: C13.1, R13.1, U6.7 (XTAL1/PB6), Y2.2
unnamed: C14.1, R13.2, U6.8 (XTAL2/PB7), Y2.1
unnamed: D8.2, F2.1, R24.1, R36.2, U7.6 (A)
unnamed: D8.1, F3.1, R24.2, R37.1, U7.7 (B)
PB0: R45.2, U6.12 (PB0)
PB1: R26.2, U6.13 (PB1)
PB2: R27.1, R48.1, U6.14 (PB2)
PB3: J4.4 (MOSI), R46.2, U6.15 (PB3)
PB4: J4.1 (MISO), R49.1, U6.16 (PB4)
PB5: J4.3 (SCK), R47.2, U1.5 (+), U6.17 (PB5)
PD0: R9.2, R42.2, U6.30 (PD0)
PD1: R11.2, R41.1, U6.31 (PD1)
PD5: R29.1, U6.9 (PD5)
PD6: R30.1, U6.10 (PD6)
PD7: R38.1, U6.11 (PD7)
PE0: U6.3 (PE0), U7.1 (RO)
PE1: U6.6 (PE1), U7.4 (DI)
PWRIN: C20.1, D3.2, D7.1 (K), Q1.3 (D)
USBVCC: F1.1, Q2.3 (D), U4.31 (UVCC)
VIN: C6.1, D3.1, R1.1, U5.3 (VI)

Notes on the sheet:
Not used Pins At ATMEGA16U2-A And ATmega328PB-A Firmware method (preferred): Make them outputs driving LOW right after reset.
Auxiliary I/O Expansion Port
In firmware not used GPB0-GPB7, configure them as outputs driving LOW (recommended)
4-Channel Low-Side MOSFET Switching Stage with Flyback Protection
RS-485 Communication Transceiver
MCP23017 CONNECT IN PARRALLEL WITH SDA AND SCK ON ATMEGA 328PB-A
DI is connected to PD4 in parrallel
I²C GPIO Expander Module (MCP23017)
INTA connected to PD2 on ATmega 328PD-A INTB connected to PD3 on ATmega 328PD-A

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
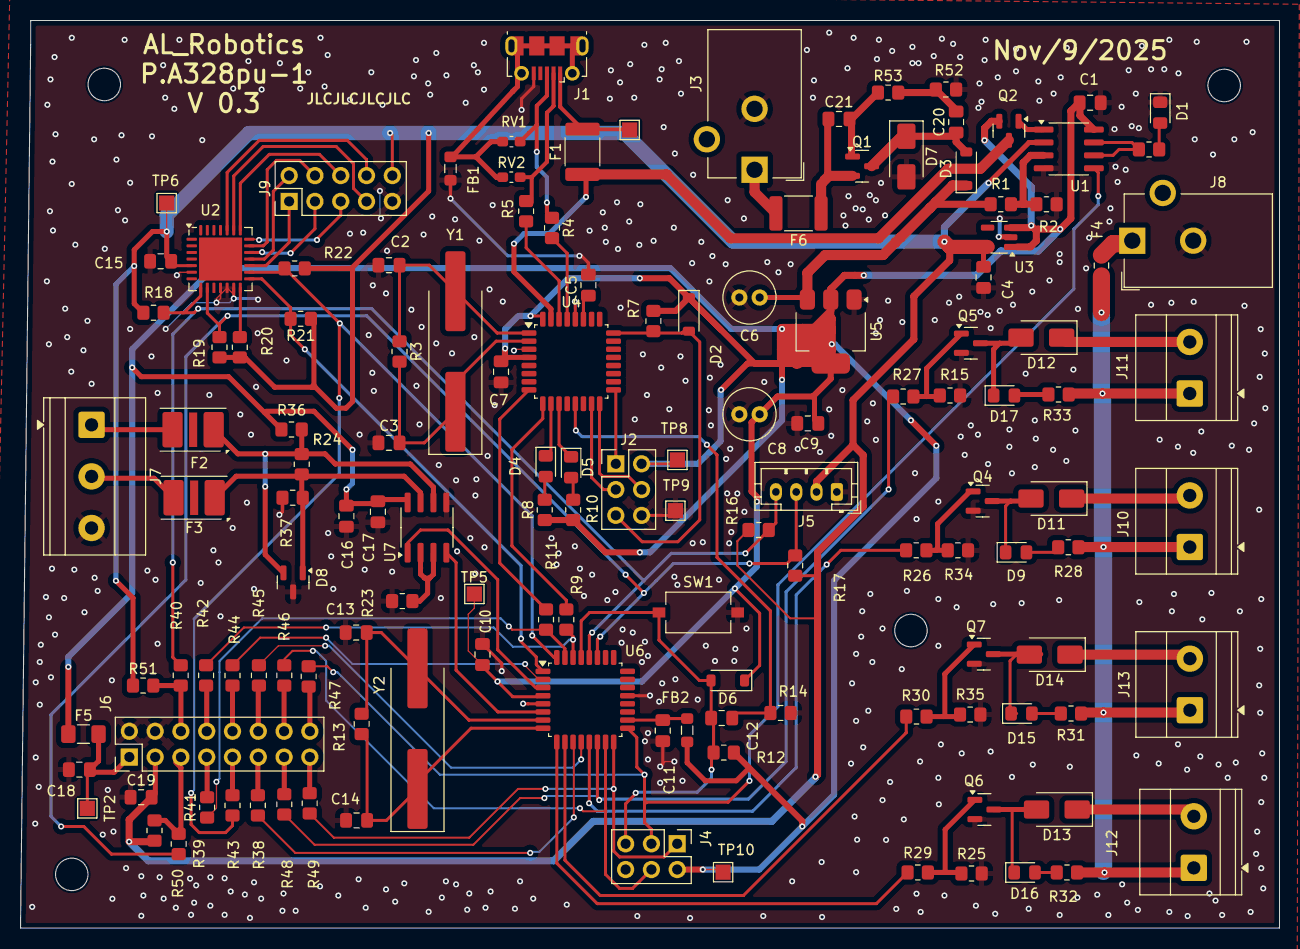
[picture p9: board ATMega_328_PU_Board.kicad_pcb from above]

Board: 4 copper layers, 124.0 x 89.4 mm, 140 parts (0 on the bottom side), 101 nets.

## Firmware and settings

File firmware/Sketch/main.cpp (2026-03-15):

#include <Arduino.h>
#include <Wire.h>
#include <LiquidCrystal.h>
#include <Adafruit_MCP23X17.h>

// ---------------- LCD wiring (unchanged) ----------------
#define LCD_RS  8    // PB0
#define LCD_E   13   // PB5
#define LCD_D4  10   // PB2
#define LCD_D5  11   // PB3
#define LCD_D6  7    // PD7
#define LCD_D7  4    // PD4

LiquidCrystal lcd(LCD_RS, LCD_E, LCD_D4, LCD_D5, LCD_D6, LCD_D7);

// ---------------- MCP23017 ----------------
Adafruit_MCP23X17 mcp;
static constexpr uint8_t MCP_ADDR = 0x20;

// Button on MCP: GPA4 (J9-5) -> GND
static constexpr uint8_t BTN_PIN = 4;   // GPA4

// Motor OUT1 gate is PB1 -> Arduino D9
static constexpr uint8_t MOTOR_GATE_PIN = 9; // PB1 (controls Q4 / J10)

// Debounce (non-blocking)
static constexpr uint32_t DEBOUNCE_MS = 25;

bool motorOn = false;

// For edge detect + debounce
bool lastRaw = HIGH;       // raw button level (HIGH released, LOW pressed)
bool stable = HIGH;        // debounced stable level
uint32_t lastChangeMs = 0; // time raw last changed

void showStatus() {
  lcd.setCursor(0, 0);
  lcd.print("AL_Robotics     ");
  lcd.setCursor(0, 1);
  lcd.print("Motor: ");
  lcd.print(motorOn ? "ON " : "OFF");
  lcd.print("        ");
}

void setup() {
  delay(100);
  lcd.begin(16, 2);
  lcd.clear();
  lcd.print("AL_Robotics");
  lcd.setCursor(0, 1);
  lcd.print("Init...");

  Wire.begin();

  if (!mcp.begin_I2C(MCP_ADDR)) {
    lcd.clear();
    lcd.print("MCP23017 FAIL");
    lcd.setCursor(0, 1);
    lcd.print("Check I2C");
    while (true) {}
  }

  // Button input + enable MCP pull-up
  mcp.pinMode(BTN_PIN, INPUT);
  mcp.digitalWrite(BTN_PIN, HIGH); // enables pull-up

  // Recommended: GPB0..GPB7 outputs LOW
  for (uint8_t p = 8; p <= 15; p++) {
    mcp.pinMode(p, OUTPUT);
    mcp.digitalWrite(p, LOW);
  }

  // Motor gate
  pinMode(MOTOR_GATE_PIN, OUTPUT);
  digitalWrite(MOTOR_GATE_PIN, LOW);

  // Init debounce state
  stable = mcp.digitalRead(BTN_PIN);
  lastRaw = stable;
  lastChangeMs = millis();

  motorOn = false;
  showStatus();
}

void loop() {
  const uint32_t now = millis();

  // Read raw button
  const bool raw = mcp.digitalRead(BTN_PIN); // HIGH=release, LOW=pressed

  // Track raw changes
  if (raw != lastRaw) {
    lastRaw = raw;
    lastChangeMs = now;
  }

  // If raw has been stable long enough, accept as debounced state
  if ((now - lastChangeMs) >= DEBOUNCE_MS && raw != stable) {
    stable = raw;

    // Trigger on PRESS event (transition to LOW)
    if (stable == LOW) {
      motorOn = !motorOn;
      digitalWrite(MOTOR_GATE_PIN, motorOn ? HIGH : LOW);
      showStatus();
    }
  }
}

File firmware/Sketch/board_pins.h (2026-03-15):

#pragma once
#include <Arduino.h>

// ------------------------------------------------------------
// Al_Robotics — ATmega328PB @ 16 MHz (MiniCore pin mapping)
// ------------------------------------------------------------
// UART0 (PD0/PD1) <-> ATmega16U2 USB bridge
constexpr uint8_t PIN_RX0 = 0;    // PD0 (USART0 RXD)
constexpr uint8_t PIN_TX0 = 1;    // PD1 (USART0 TXD)

// I2C bus (Wire)
constexpr uint8_t PIN_SDA = A4;   // PC4 (SDA)
constexpr uint8_t PIN_SCL = A5;   // PC5 (SCL)

// MCP23017 interrupt lines -> ATmega external interrupts
constexpr uint8_t PIN_INT_A = 2;  // PD2 / INT0  (MCP INTA)
constexpr uint8_t PIN_INT_B = 3;  // PD3 / INT1  (MCP INTB)

// RS-485 enable control (DE and /RE are tied together on the PCB)
constexpr uint8_t PIN_RS485_DE_RE = 4;  // PD4 drives MAX485 pins 2+3 (DE & /RE)

// ------------------------------------------------------------
// Notes (for reference, no defines needed here):
// * MAX485 DI  (pin 4)  -> ATmega328PB PE1 (USART1 TXD)  == Serial1 TX
// * MAX485 RO  (pin 1)  -> ATmega328PB PE0 (USART1 RXD)  == Serial1 RX
// * main.cpp selects UART at runtime (RS485UART 0|1), default = Serial1.
//
// Make sure MiniCore is set to ATmega328PB so Serial1 is available.
// ------------------------------------------------------------

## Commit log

2026-03-15 Initial commit – ATmega328 control board project
    Added KiCad PCB design, firmware, BOM, Gerber files, documentation and prototype images.
    [ATMega_328_PU_Board-B_Mask.gbs, ATMega_328_PU_Board-B_Paste.gbp, ATMega_328_PU_Board-B_Silkscreen.gbo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]
2026-03-15 Add image to README for ATmega328 Control Board
2026-03-15 Update README with prototype and hardware validation images
    Added sections for assembly, testing setup, clock verification, and power testing.
2026-03-15 Update README with prototype and hardware validation images
2026-03-17 Add Power Testing section to README
    Added Power Testing section with image.
2026-03-17 Clean up README.md power testing section
    Remove duplicate power testing information and fix image syntax.
